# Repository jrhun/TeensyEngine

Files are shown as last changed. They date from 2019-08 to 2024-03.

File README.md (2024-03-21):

# TeensyEngine

TeensyEngine is primarily the software I use for my Totem Pole - named *The Orb*. 

gif

Included in this repository is a description of both the hardware and software features, including the MCAD/ECAD designs for everything.
It includes an emulator that's using OpenFrameworks for display and UI control, allowing easy testing and development.

<details>
<summary>  The Orb in the wild 
</summary>

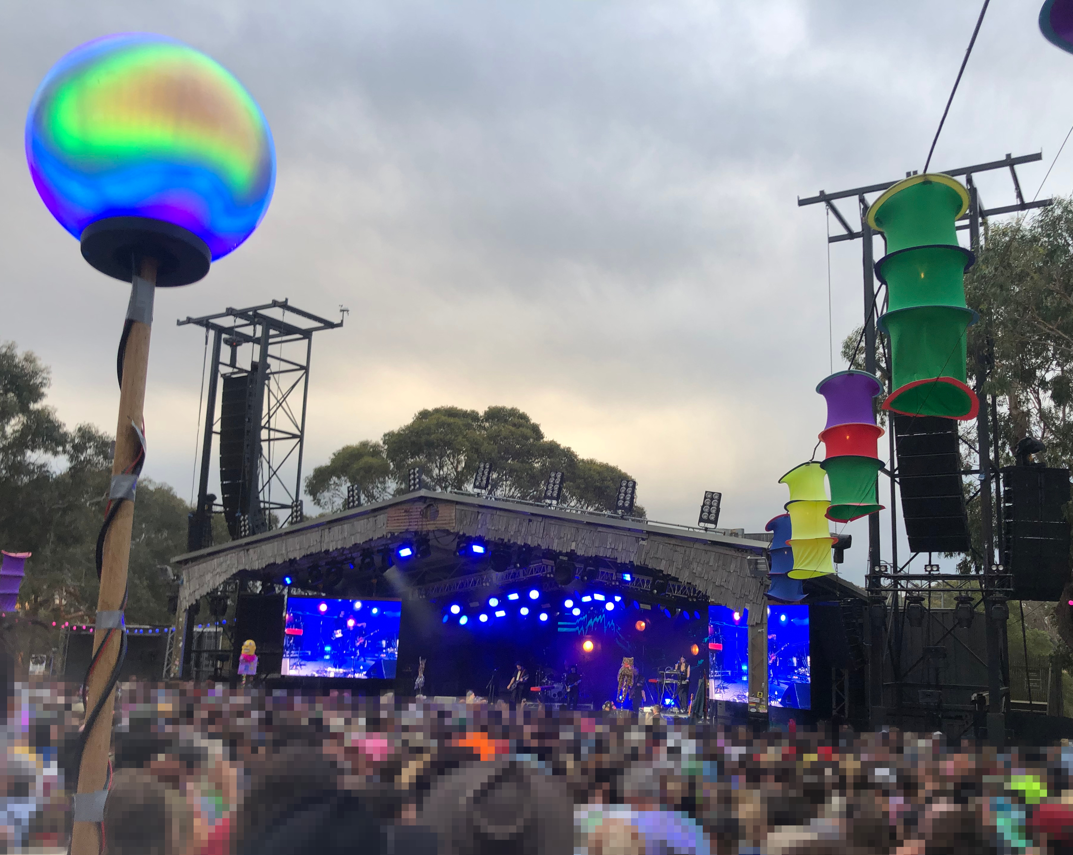
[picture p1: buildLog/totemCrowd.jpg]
totem crowd


</details>

## Contents 
- [About](#about)
- [Features](#features)
- [Hardware](#hardware)
- [Software](#software)
- [Credit](#credit)

## About
I took ~2000 LED lights and carefully shoved them inside a polycarbonate ball that was then placed on top of a stick and hooked up to a microprocessor and battery pack. Shockingly, it worked quite well! I use it as a Totem Pole for music festivals, come say hi if you see it!

This has been a multiyear endeavor  that I've slowly added more and more features to. It's the 4th iteration of the hardware including LEDs and controller/battery box. The first version was a couple of LEDs taped down inside two salad bowls - [how far this project has come since then!](buildLog/README.md#previous-versions)

Just a heads up - I'm an almost completely self taught programmer/3d modeler/electronics designer, there is a level of *jank* at times that should be expected to come of that, but overall I've been very pleased with the outcome! 
I will gladly take any suggestions or tips to improve my work, please comment any suggestions!

## Features

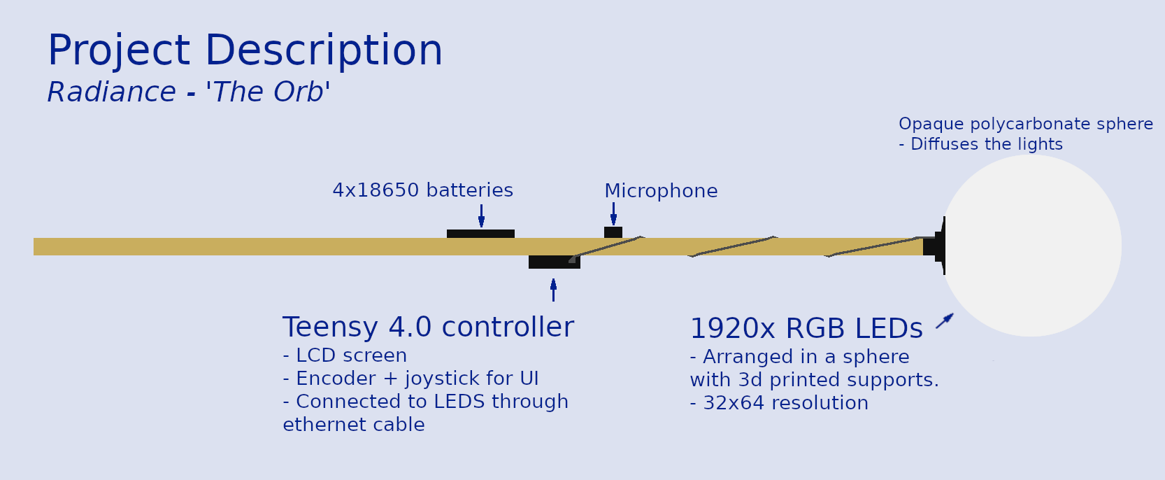
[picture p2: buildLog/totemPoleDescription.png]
description

- 25+ different patterns with the ability to change the colour palette being used for most patterns!
- Custom global blur/fade/glitter effects that can run on top of any pattern
- Text overlay onto patterns with the ability to enter custom text using the controller
- LCD Screen for changing settings/patterns + showing battery voltage and power usage
- Current sensor for monitoring power usage
- Encoder + buttons for navigating the UI
- An accelerometer (because why not)
- Microphone input 
- Wireless compatibility with NRF24L01 or ESP-01

<details open>
<summary> Videos of patterns on the hardware </summary>

https://user-images.githubusercontent.com/25134458/209674595-40512c94-f8f8-4173-94cc-6f29fc267113.mp4

https://user-images.githubusercontent.com/25134458/209741537-4713a7b6-7f0b-4868-8ff8-e278ab186450.mp4

https://user-images.githubusercontent.com/25134458/209743201-d97811d2-97b1-4fea-91a2-2c5a3d3df347.mp4

</details>

## Hardware
Some photos of the completed project can be found [here](buildLog/README.md).
I made a custom circuit board for connecting everything up along with a daughter board for [powering](#Power) the LEDs and providing the data through a CAT5 cable. 

#### Processor
A teensy 4.0 is the heart of the project, providing plenty of raw power to overcome my inefficient coding and push out LEDs while controlling  a UI.

#### Accessories
- Microphone - I can't remember what I'm using, one of the Sparkfun electret autogain boards. 
- NRF24l01 - used to connect wirelessly to LED headbands - allows you to change the patterns/brightness/colour of the headbands!
- ESP-01 - pins to connect to an ESP are broken out but not yet implemented
- ACS712 current sensor in series with the LEDs to measure power usage
- MSGEQ7 - the pinout is there but I haven't ended up using it yet
- ILI9341 colour TFT display 240x320 
- MPU9250 accelerometer

If trying to make this project, please confirm the pinout matches for the display and accelerometer! I got caught out and assumed they were the same for the two almost identical accelerometers I had, then needed to edit the circuit board. Also the linear regulator for the processor 5V line got way too hot so I changed it for a small buck convertor that (roughly) matched it's footprint. To be honest the circuit board could be redone with a teensy 4.1, as soldering the pogo pins to connect to the back of the teensy 4.0 was very tedious. 

#### Lights
Custom 3d printed scaffolding for strips of SK6805-2427 RGB LEDs, to hold them in a spherical shape inside a polycarbonate ball 25cm in diameter. They're held slightly back from the inside of the sphere to help diffuse the lights nicely. The scaffolding press fits together and tolerances were set for my 3d printer - YUMV. They're also held in place under slight compression from the globe. The LED strips are arranged as 30 to a strip with an offset pattern to reduce crowding at the poles, allowing for an effective resolution of 32H x 64W. See the [build details](buildLog/README.md#leds) for photos. 

The lights are from [Aliexpress](https://www.aliexpress.com/item/32818340106.html?spm=a2g0o.order_list.order_list_main.358.679f1802EQyb32), and were chosen for their high density (120/M, 8.33mm pitch) and thin strips (6mm width). 
Lights with a smaller pitch and thinner strip were outrageously expensive at the time I was purchasing LEDs, but have since come down in price somewhat... Version 5 [TBC](https://www.aliexpress.com/item/1005003798198621.html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)?

#### Power
The whole thing is powered by 4x 18650 batteries, I usually carry a spare set of 4x batteries for each night that it's used which usually lasts the night through.
There's a step-down converter in the controller providing 5V for the teensy and accessories. The full battery voltage is sent up to the LEDs where there is a separate step-down convertor. The benefit of the two power supplies is efficiency and stability, having a separate power source for the controller means its voltage doesn't dip when the LEDs draw a bunch of power. It also means I can provide much more power than *most* USB powerbanks, although I do want to try sending 20v from a 100w USB-C powerbank to the LEDs. Further details in the [build section.](buildLog/README.md#power)

## Software
The software include a basic emulator that runs the same UI and pattern software using OpenFrameworks to display the LEDs. 

<details open>
  <summary>Videos of the controller</summary>
 
  https://user-images.githubusercontent.com/25134458/209736586-94fa050d-8a2f-43fb-920e-38acb0f2c6ba.mp4
  
  https://user-images.githubusercontent.com/25134458/209676572-e61da54b-b9a8-4b95-bfd1-fcbd3a2c399e.mp4
  
</details>

### UI Pages
I've tried to organise the UI controls into roughly similar pages. The current battery voltage and current draw is shown in to top right corner, and the current FastLED FPS reading in the bottom right corner. The name of the totem is on the top of the screen, then the current page and a depiction of what page you're on. Joystick left/right changes the page, and up and down to select a setting. Hovering over a setting allows you to change a value with the encoder, or for some settings such as picking a pattern or palette you can press the joystick to enter a menu for that listing options. 

- **Pattern controls**
  - Select desired patterns from the list of patterns
  - Change overall brightness
  - Select a tempo + tap tempo
  - Change the tempo oscillator between square/ramp/sine etc...
  - Trigger ability to change a patterns settings (e.g. trigger different settings for a pattern without making a complete new one, see )
- **Colour controls**
  - Change current palette with a palette preview option
  - Blend amount when changing palette  over - quick or slow blend
  - Change how fast colours from a palette are cycled through
- **Text/FX controls**
  - Add transparent or opaque text over any pattern, or just blink text 
  - Text scroll speed
  - Select the text from a list or enter custom text (12 char max only!)
  - Global blur/fade/glitter effects
- **Wireless controls**
  - Control the wireless headbands I made using NRF24L01 communication
  - Change the pattern/colour/brightness of headbands in range
- **General settings**
  - LCD Backlight/Dither/Colour temp/Accelerometer/Save/load settings

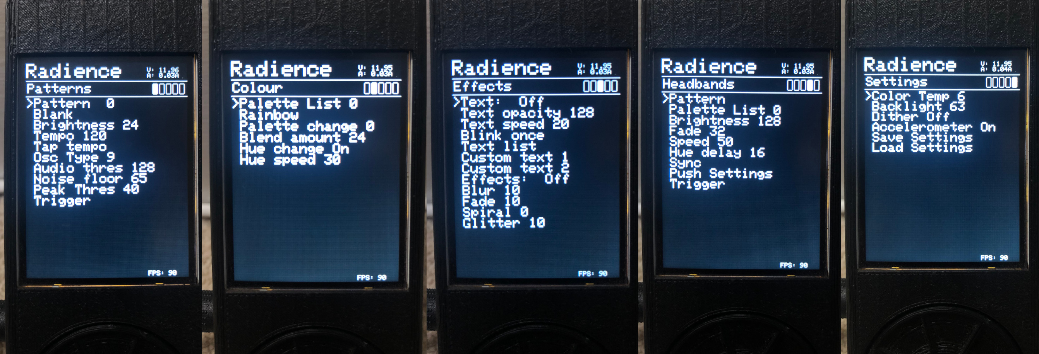
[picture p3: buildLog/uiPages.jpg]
UI example


### Adding a new pattern
The basic format for a pattern is a class inheriting from the `_Pattern` class, and should have the name for the pattern passed to it.

A `drawFrame()` function should be provided that is called to run the pattern. You can set the delay in msec for when to draw the next frame by the value you return. It also provides functions that are automatically called when starting or stopping a pattern, and a trigger option. Helper functions for drawing to the LED matrix are in the `gfx` class from `Graphics.h`. Try using `gfx.getColour(uint8_t offset)` for colours because this links in to the palette system. 

Include the code for a new pattern in `src/patterns/PatternController.h`, then add it as a member to the `PatternController` class and include it in the `patternList`
<details>
<summary>Example pattern</summary>
  
#### Blink all LEDs on/off
  ```
  class PatternBlink : public _Pattern {
  public:
    PatternBlink() : _Pattern("Blink") {}
    uint8_t drawFrame() {
      if (++count > 100) {
        count = 0;
        flip != flip;
      }
      if (flip) gfx.fill(gfx.getColour());
      else      gfx.fill(CRGB::Black);
      return returnVal; //default 10, 1000/10 = 100fps
    }
    uint8_t count = 0;
    bool flip = false;
  };
  ```
</details>

## Arduino code
The Teensyduino core was used for compiling and uploading.
`Graphics.h` does all the heavy lifting for helper functions. 

Arduino libraries used:
- [ILI9341_t3n](https://github.com/KurtE/ILI9341_t3n)
- [Encoder](https://github.com/PaulStoffregen/Encoder/blob/master/Encoder.h) from Paul Stroffregen
- [MPU9250](https://github.com/kriswiner/MPU9250) from kriswiner
- [FastLED](https://github.com/FastLED/FastLED)
- [Teensy ADC](https://github.com/pedvide/ADC)
- [RF24](https://github.com/nRF24/RF24)

## PC Emulator 

https://user-images.githubusercontent.com/25134458/209675905-0a1664af-fdfa-492f-b072-93c58537c89a.mp4

#### Requirements 
OpenFrameworks 0.10.1 was used for the graphics, with the ofxGui addon.

Visual Studio 2019 was used for compiling.
At one point I had it compiling on Mac XCode, but I haven't checked if that still works in a while.

<details open>
  <summary>The emulator has keyboard controls for the UI:</summary>
  
  - WASD: joystick up/left/down/right
  - Q/E: encoder rotate clockwise/counter clockwise
  - F: joystick press 
  - space: separate trigger, triggers effect on certain patterns (calls Pattern::Trigger())
  - Home/End/Del/PgDown: change pitch/roll level to emulate accelerometer changes
  - I: add random impulse to accelerometer data
  - 1 through 7: change beat type (RAMP, INVERSE_RAMP, TRIANGLE, SQUARE, SIN, TRIGGER, GATE, AUDIO, AUDIO_AVG, OFF)
</details>

## To-do list
- [ ] Add more photos of the completed totem to the build log
- [ ] More patterns
- [ ] Accelerometer fluid simulation - I've had multiple attempts but it just doesn't look right, a little beyond my abilities currently!
- [ ] More audio responsive patterns/improving audio code
- [ ] More patterns to respond to accelerometer 
- [ ] Make better use of global effects - the LEDs are double buffered but this is only really used for text currently
- [ ] Rotatable 3d view of the totem in the emulator rather than displaying as a flat 2d matrix

## Credit 
This project has taken inspiration from countless different sources. Please see [CONTRIBUTIONS.md](CONTRIBUTIONS.md) for full details.

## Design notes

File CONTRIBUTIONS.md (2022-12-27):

# Contributions

This project has been ongoing for years, I've taken bits and pieces of code that I've found useful or interesting and either used them as is, changed parts to fit, or re-written it completely. 
Unfortunately, much time has passed and I'm now I'm not entirely sure what parts are a complete rip off and what's original. 
If you see any of your code that I've used and not given credit for, please contact me so I can provide proper credit!

### 3d Engine Inspiration
[The Chili Framework 2016/3d Fundamentals]([https://github.com/planetchili/chili_framework](https://github.com/planetchili/3D_Fundamentals/tree/master/Engine)) was used as a basis for the 3d rendering code and helped me learn a lot about how a renderer works! The Chili Framework is under the same GNU General Public License v3.0 as the project.

### FastLED
FastLED is under the [MIT License](
MIT-License.md) (Copyright (c) 2013 FastLED). Various aspects of FastLEDs source code were copied for use with the emulator (essentially just any arduino references were removed). 

### Teensy core
Teensyduino is under the  GNU GENERAL PUBLIC LICENSE Version 2

### MPU9250 code
Example code taken from MPU9250_LPS25H_t3 by Kris Winer (license: Beerware)

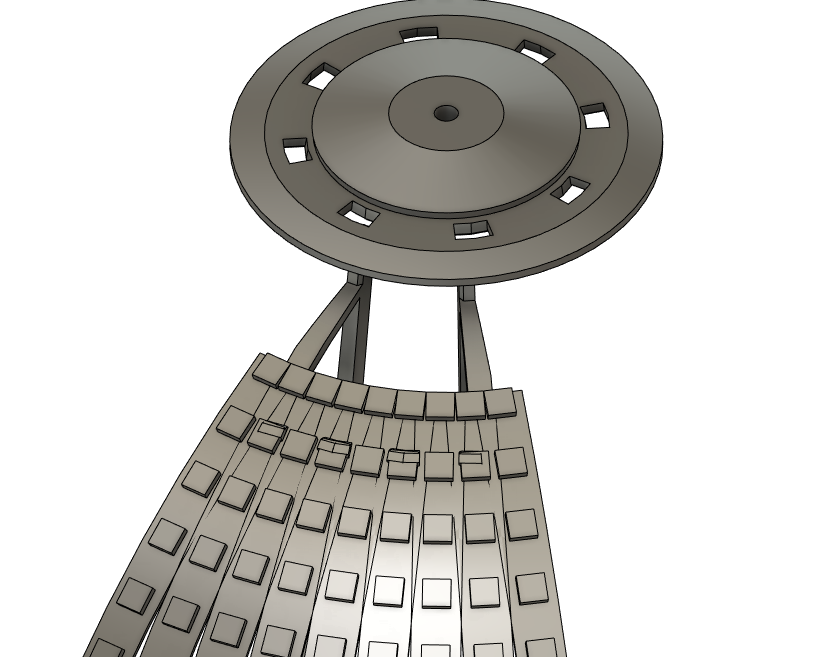
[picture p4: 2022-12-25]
buildLog/design-topLeds.PNG

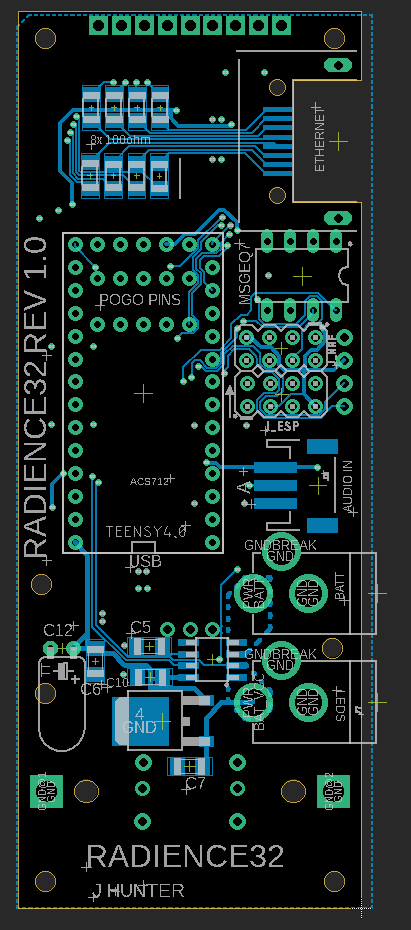
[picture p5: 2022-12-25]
buildLog/PCB_design-back.PNG

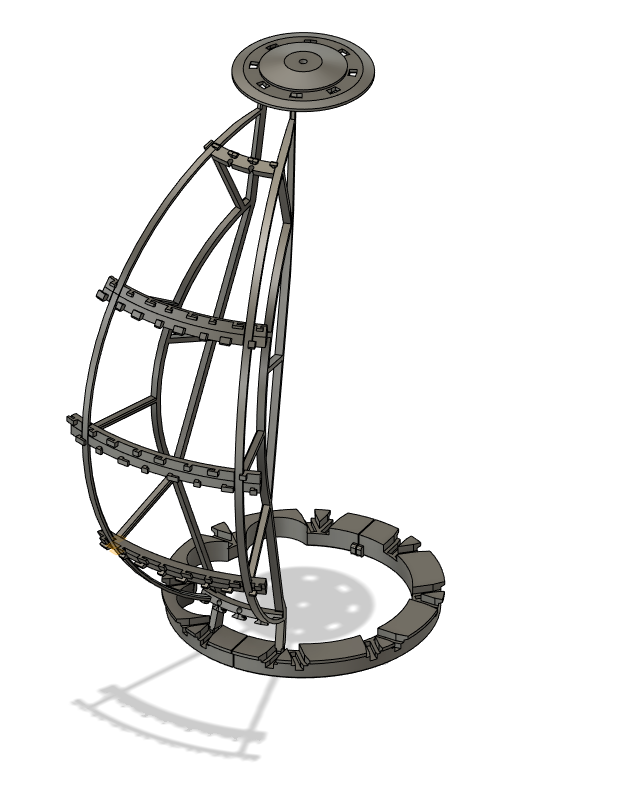
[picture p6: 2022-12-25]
buildLog/designSection.PNG

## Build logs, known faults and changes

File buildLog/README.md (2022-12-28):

# Build Log

## Contents
- [LEDS](#leds)
- [Power](#power)
- [Controller](#controller)
- [Previous Versions](#previous-versions)

## LEDS
I wanted as many LEDs as possible, and I wanted them held back enough from the polycarbonate shell to diffuse them nicely. 
I 3d modelled some scaffolding using ideas that had worked well from my previous attempts. The pieces press fit together, and once the LEDs are on, they're held in place quite firmly. It's built in 8 sections in order to fit inside the opening for the polycarbonate sphere (Only a ~10cm opening!), with a top and bottom piece to hold it in place. The top section can be tightened against the shell to help hold everything snug. 

### 3d Modelling the LEDs
This was one of the most complex models I'd made thus far, I needed to split the design up into sections that could break apart and be reconnected inside the globe, but I didn't want anything touching the sides as this would cast shadows and be visible (something V3 showed). This meant it needed a lot of rigidity to sandwich it inside the sphere from the top and bottom and not move around. I also found it difficult to model all the curves, there's not a lot of straight lines in this design and a lot of extruding along a path, meaning many extra steps for a simple feature.

I tried to design the profile to give as much space in the centre for my hand for getting inside, but still maintaining rigidity.
You can see how the LEDs interfere which each other at the top - it's wasted resolution up the top/bottom anyway and it gets crowded up there which is why the LEDs are offset from each other. 

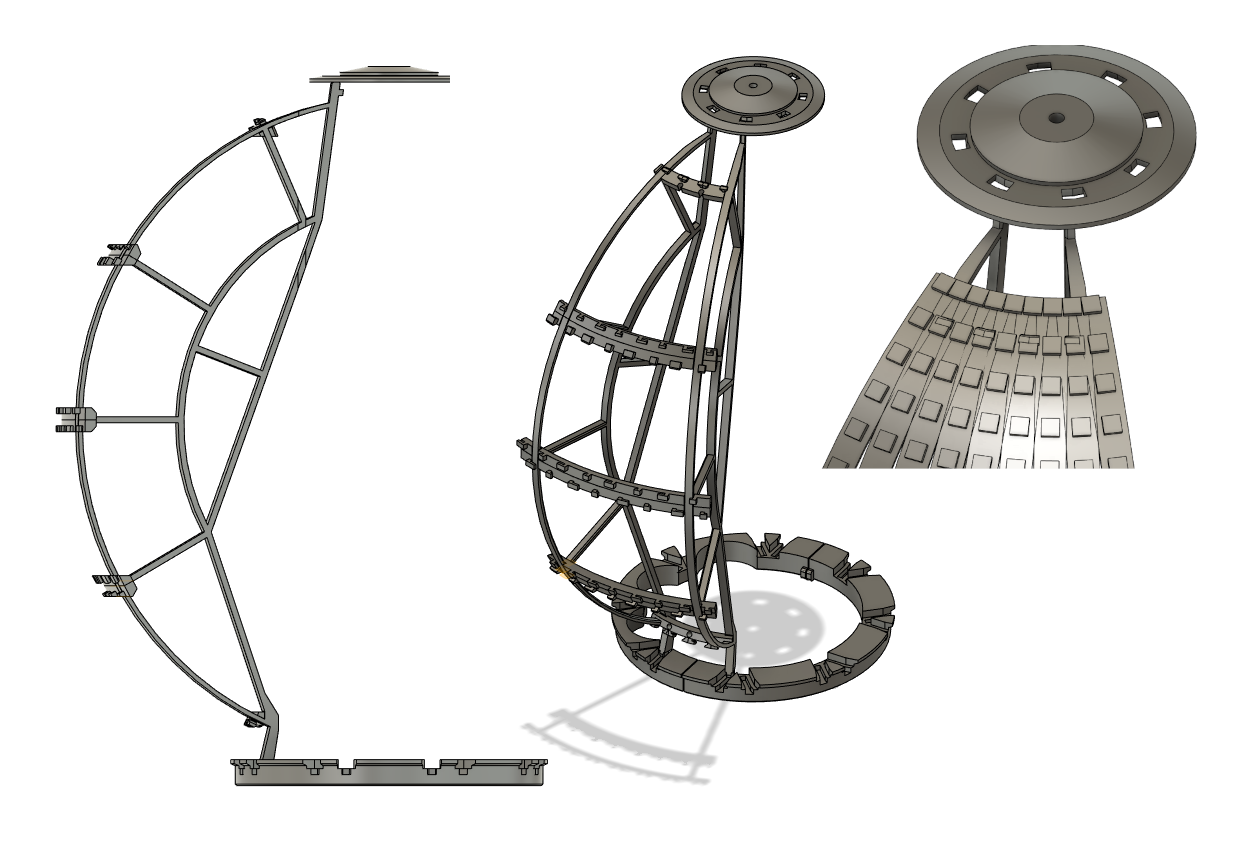
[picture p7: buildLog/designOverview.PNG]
Overview


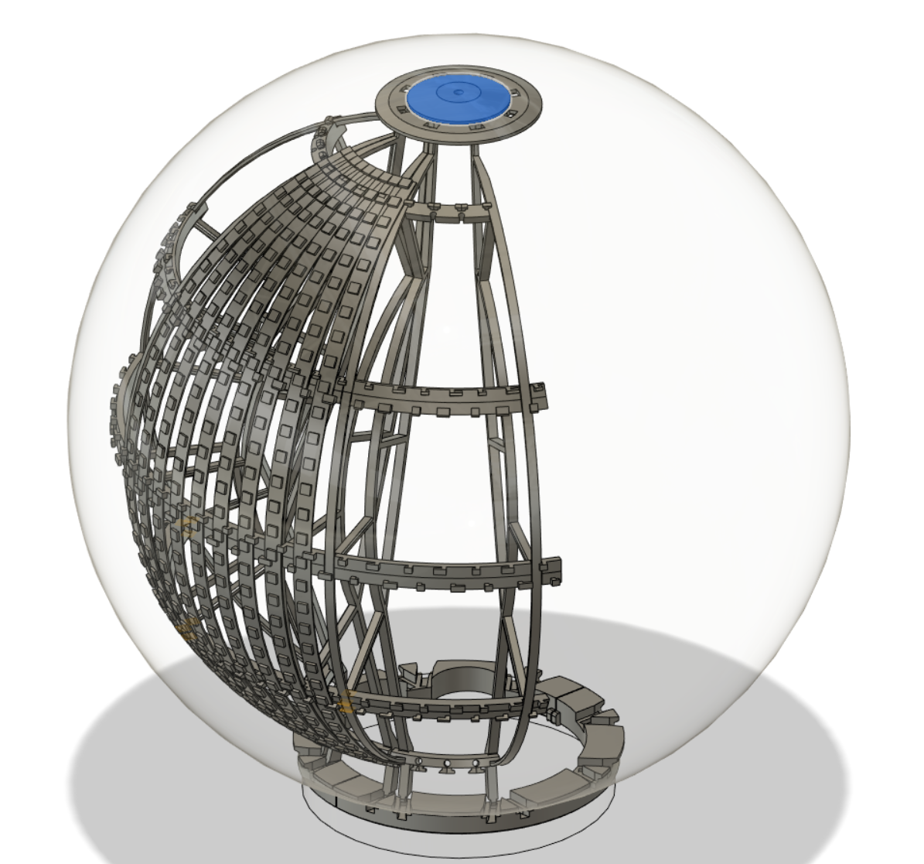
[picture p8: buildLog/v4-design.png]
Design


### Building the LED holders. 
One of the 8 sections printed. 

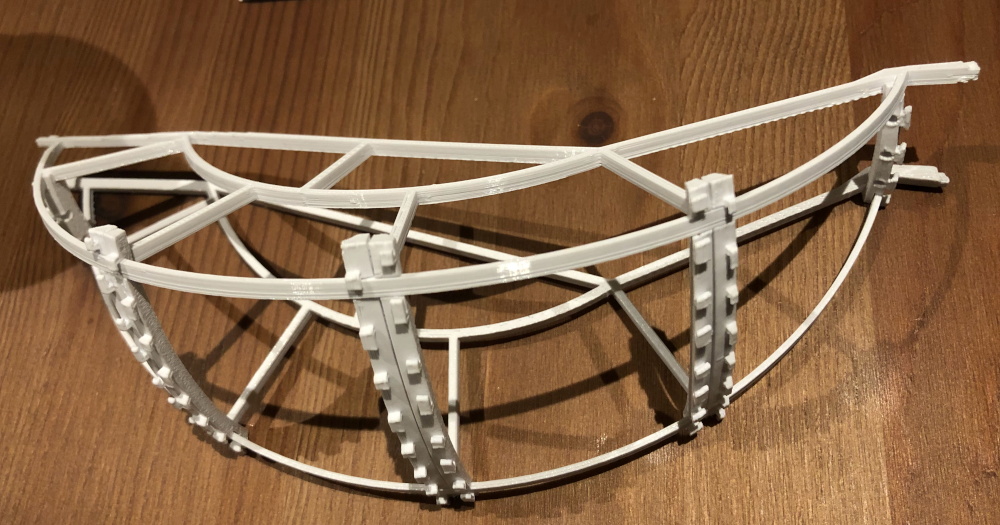
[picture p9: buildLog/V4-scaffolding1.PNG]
Scaffolding


These are SK6805-2427 RGB LEDs from [Aliexpress](https://www.aliexpress.com/item/32818340106.html?spm=a2g0o.order_list.order_list_main.358.679f1802EQyb32), the strips have a pitch of 8.33mm (120 LEDs per metre), and are only 6mm wide! In total I used 64x strips of 30, with separate power and data lines to each section of 8x strips. I won't lie, it took a long time to cut/strip the wires and solder everything all together, I probably didn't need to but I also added extra connections throughout the strips for distributing power/ground around and added stability in holding everything in place. 

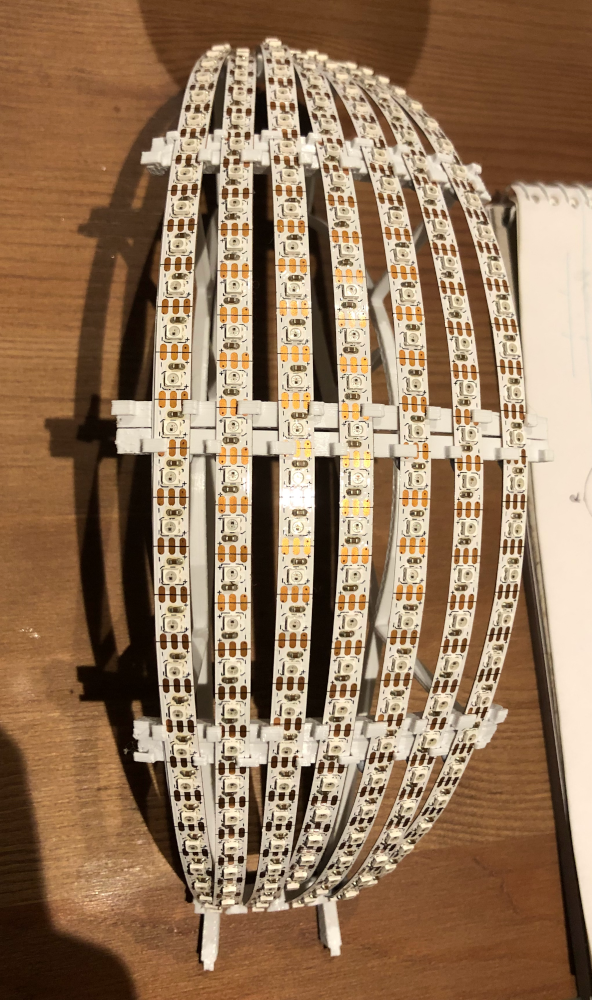
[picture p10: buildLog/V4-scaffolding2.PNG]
Scaffolding


Test fit of everything together. You can see how the LEDs are offset from each other to make space at the top/bottom. 

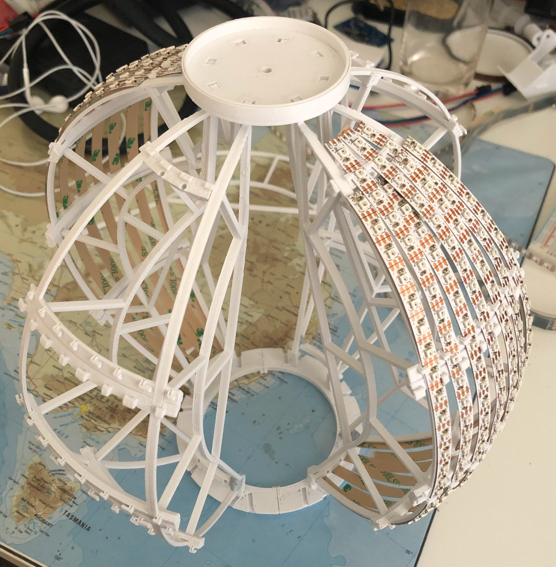
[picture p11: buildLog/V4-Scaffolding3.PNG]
Scaffolding


Checking if the LEDs all light up and my matrix XY() code works.
  
https://user-images.githubusercontent.com/25134458/209637888-4b88d217-abbb-4099-afa3-3a01516f0b0f.mp4

https://user-images.githubusercontent.com/25134458/209641775-9f14f9cc-60d3-4ed1-b838-ff2e159a5c03.mp4

Once I had each section built and connected, they needed to somehow be placed inside the shell and properly lined up. It was like building a ship in a bottle, but with lots of careful squeezing and manoeuvring all 8 sections were somehow in place and could be connected up to the bottom support to hold them in place. 

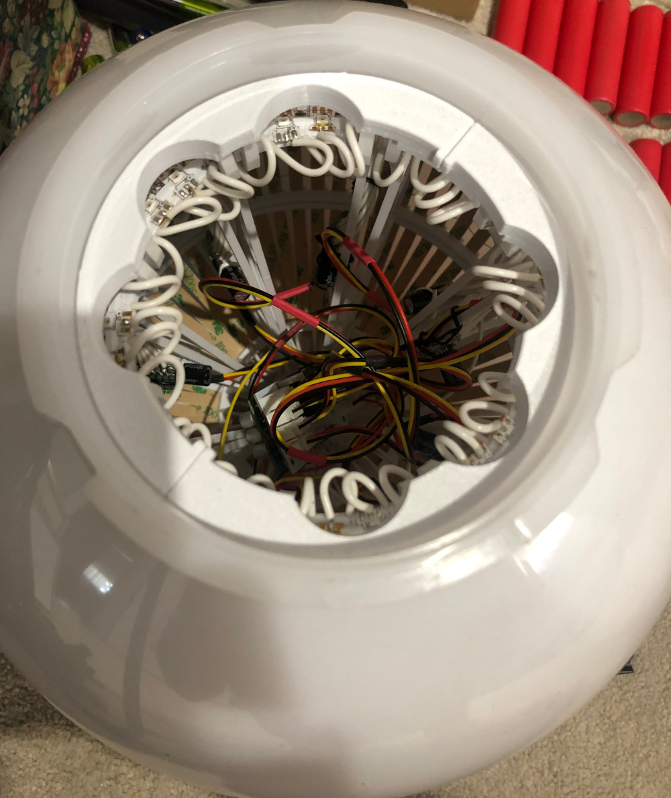
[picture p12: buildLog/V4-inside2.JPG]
Inside


I'm really happy with how the diffusion effect turned out, the lights are held back at almost the perfect distance. 

https://user-images.githubusercontent.com/25134458/209674595-40512c94-f8f8-4173-94cc-6f29fc267113.mp4

## Power
Previously I had powered V1 and V2 from initially 2xAA batteries. V3 kicked it up a notch going up to 288 LEDs so I went with 4xAAA batteries, but it still struggled if I turned up the brightness and would glitch out or freeze. It worked okay for V3 but moving up to ~2000 LEDs I needed something stronger. 

I used 4x 18650 batteries in a standard holder from amazon and changed it to a the barrel connector. The full battery voltage is sent up a wire to the LEDs at the top of the pole, and plugs into the daughter board up there. This allowed me to send the full battery voltage (~15V) up to the LEDs without needing a heavy gauge wire. There's a beefy [Pololu D24V150F5](https://www.pololu.com/product/2881) 5V 15A buck converter up there that does an amazing job for its size. This thing is expensive (and seems to have almost doubled in price since I bought one - ouch) but can handle up to 15A at 5V reliably and pretty efficiently, which is important since the LEDS draw ~0.5A (at 15V!) even when off with just their standby current! I guess 0.8ma per led adds up when there are 1920 of them... There's a separate step-down converter in the controller which avoids software freezes and glitches ~~if~~ when the LEDs draw too much current and dip the voltage. 

The connection for the LEDs is an ethernet cable, like with the [Teensy OctoWS2811](https://www.pjrc.com/store/octo28_adaptor.html). In theory, you should be able to connect an OctoWS2811 directly to the daughter board without any issues since I've used the same circuit as the OctoWS2811 to output data lines from the Teensy. Having 8 independent LED sections allowed 8 data wires for parallel output and a reasonable framerate, using a single data line for 1920 LEDs would have resulted in a framerate < 10fps.  

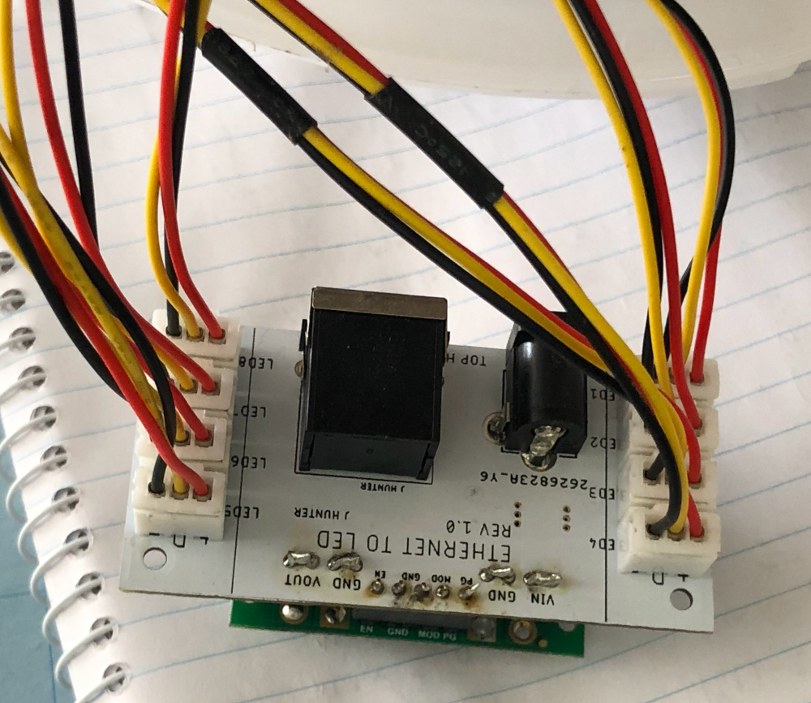
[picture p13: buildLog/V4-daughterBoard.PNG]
Daughter board


To avoid an absolute rats nest of wires at the top and bottom of the strips (128 wires for power/ground + data lines... no thanks!), I injected power into the middle of the strips. Each section of 8x strips (8 sections total) gets a data/power/ground connection from the daughter board, which goes to a small piece of protoboard with a capacitor and 8 ground/power wires for each strip. 

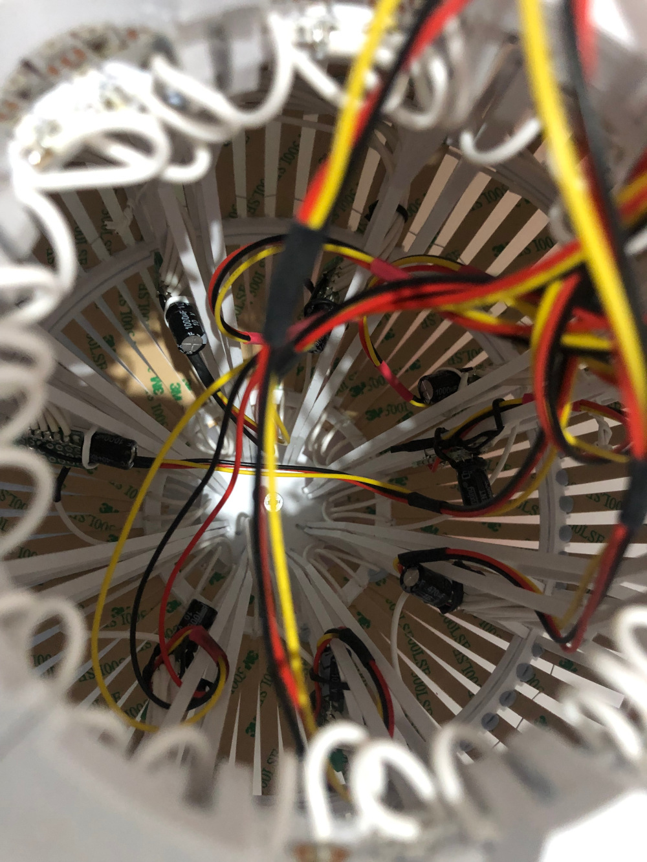
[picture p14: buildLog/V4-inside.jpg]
Inside


## Controller
I found a much larger 240x360 colour TFT that was the basis for the new controller, version 3 had a tiny 128x64 OLED screens that was monochrome and almost useless due to it's small size. It's much nicer actually being able to see the screen and having a colour screen allowed for a preview of the colour palettes. 

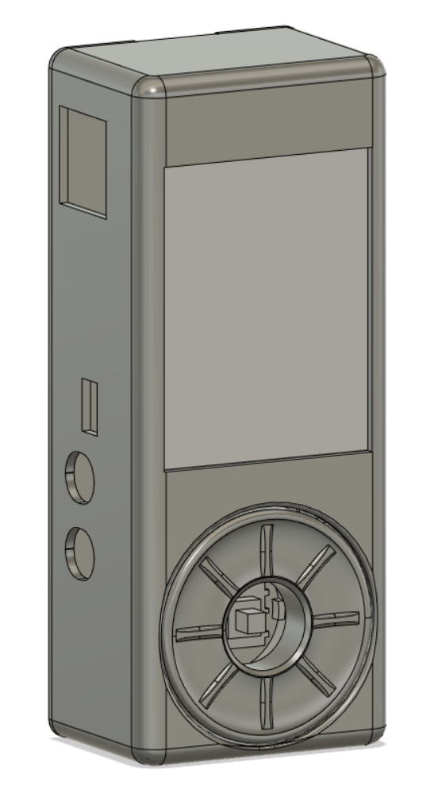
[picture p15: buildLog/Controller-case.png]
Case


I wanted input controls similar to an iPod classic, but designing a capacitive encoder seemed overkill and likely to become its own project, so I settled for a hollow encoder with a joystick in the centre. I was testing everything with an ESP32 initially, which worked okay but was missing some grunt. Around this time the Teensy 4.0 was released and it blew everything else out of the water performance wise, I pivoted over to use it instead and I'm so glad I did. 

The controller has pinouts for a NRF24L01, I've used this to connect to a set of headbands I made and can transmit colour/pattern change messages to them. 

<details open>
  <summary>Headbands details/photos</summary>
  
  The headbands have a mere 14 LEDs on them in a waterproof casing, connected to a small circuit board that holds an ATTINY and an NRF24L01, powered by 2xAA batteries in a 3d printed case. The case is a little bulky but has a nice curve that conforms to the back of your head. It's proven to be a pretty sturdy design, none of the 12 I made have broken yet... A couple patterns and the NRF code is at the limit of what the ATTINY can do, though it's impressive for a DIP8 chip! Technically powering the LEDs from 3V shouldn't work and I was prepared to squeeze a boost converter in there, but I got lucky and it worked fine for the LEDs I had on hand! 
  
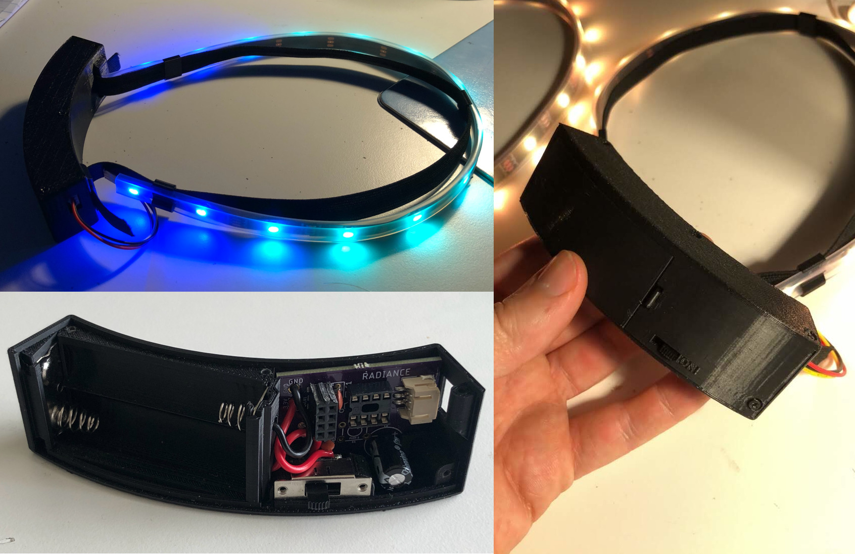
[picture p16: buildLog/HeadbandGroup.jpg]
  
  
  </details>

## Previous versions
### Version 1  
The initial design for a Totem poll called for lasers shining on a crystal in the centre, in an attempt to get a bunch of refraction and look interesting. This did not work at all. Luckily I had added a handful of WS2812 LEDs around, and at the last minute tapped them to the bottom so it at least lit up somewhat brightly. I  had spray painted the pole and bowls which was a poor choice as it would rub off onto your hands and made everything tacky - truly terrible!

### Version 2 
I scrapped the lasers, but went big on the LEDs which had worked the best. I found these excellent partially opaque polycarbonate shells 25cm in diameter, and tapped 9x strips of 8 WS2812 LEDs to the inside of it. It was much better than V1, but the tape came loose during the festival and some of the strips weren't always sitting up against the shell. This looked better than and ended up giving a nice diffuser effect to these lights to make them less of a pinpoint of light, giving me the inspiration for V3. 
  <details> 
    <summary>Photos</summary>
  
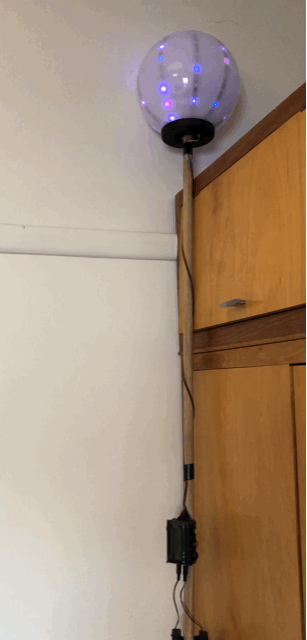
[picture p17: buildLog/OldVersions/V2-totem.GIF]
Version 2
  
  
  </details>
  
### Version 3 
This was where I started to get serious. If 72 LEDs looked so good, what if I had 4x as many?  I used 16x strips of 18 WS2812 leds, and 3D printed brackets to hold the LEDS in place and off the shell to get the diffuser effect. I designed my first circuit board for the control box to tidy things up and 3d printed a case for it as well. This version had enough resolution to even write basic words on it, but I knew I could squeeze in more LEDs if I tried...

  <details> 
    <summary>Photos</summary>
  
  Here you can see the layout of the LEDs, with the top piece holding them in place, and a spacer in the middle resting against the sphere shell. The 4 rods hold up the center piece, but it was too bulky and these rods too flimsy to keep reasonable tension. The middle spacers worked well but the part up against the shell cast a shadow from the LEDs to the side of them. This design had a lot of snap fits which worked surprisingly well overall. 
  
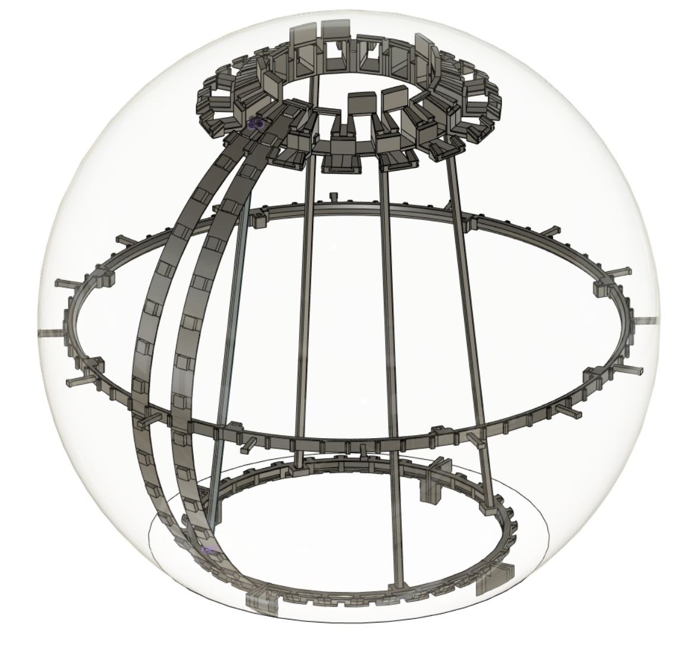
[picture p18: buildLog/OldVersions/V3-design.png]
Version 3
  
  
   You can see how the support rods are bending and the obligatory token capacitor for WS2812 leds. 
  
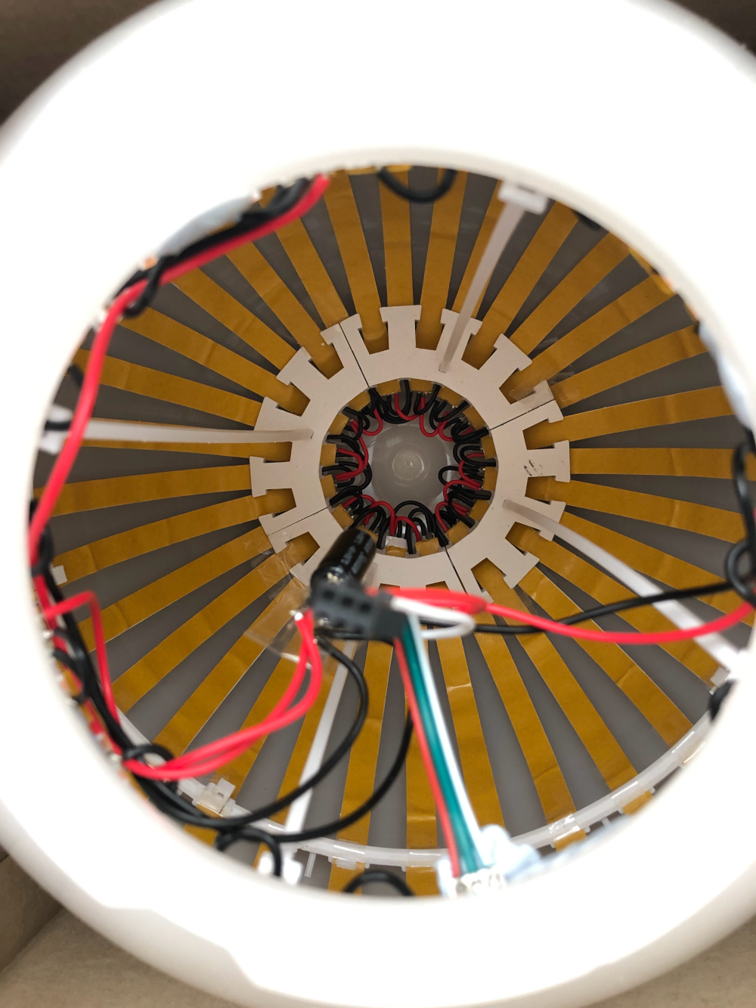
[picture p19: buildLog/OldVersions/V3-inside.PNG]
Version 3
  

https://user-images.githubusercontent.com/25134458/209637023-156c7152-dfb4-41f7-a652-bb55d0df1f59.mp4

  </details>

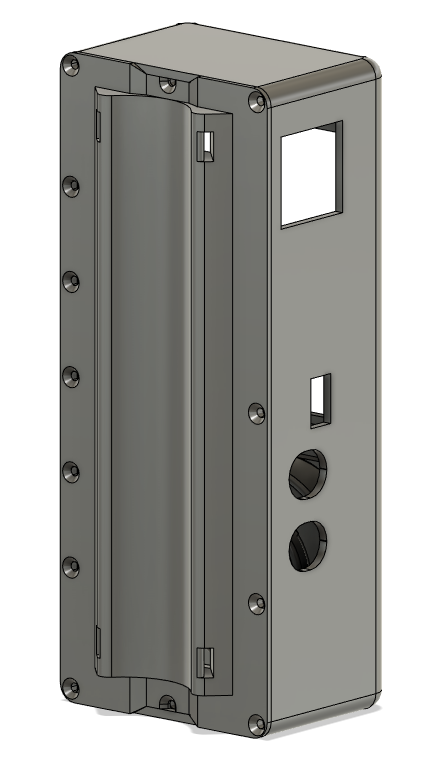
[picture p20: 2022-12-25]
buildLog/Controller-case-back.PNG

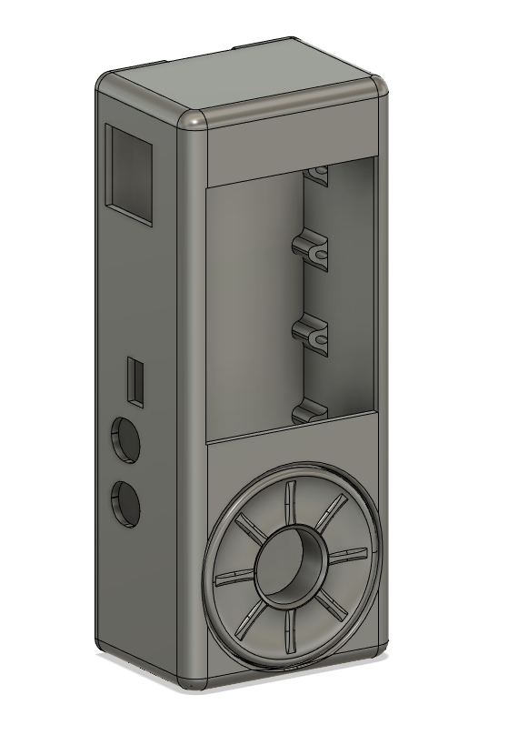
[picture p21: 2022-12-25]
buildLog/Controller-case-front.PNG

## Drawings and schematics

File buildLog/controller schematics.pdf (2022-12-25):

# 5 P$1 GND@¹*2

A

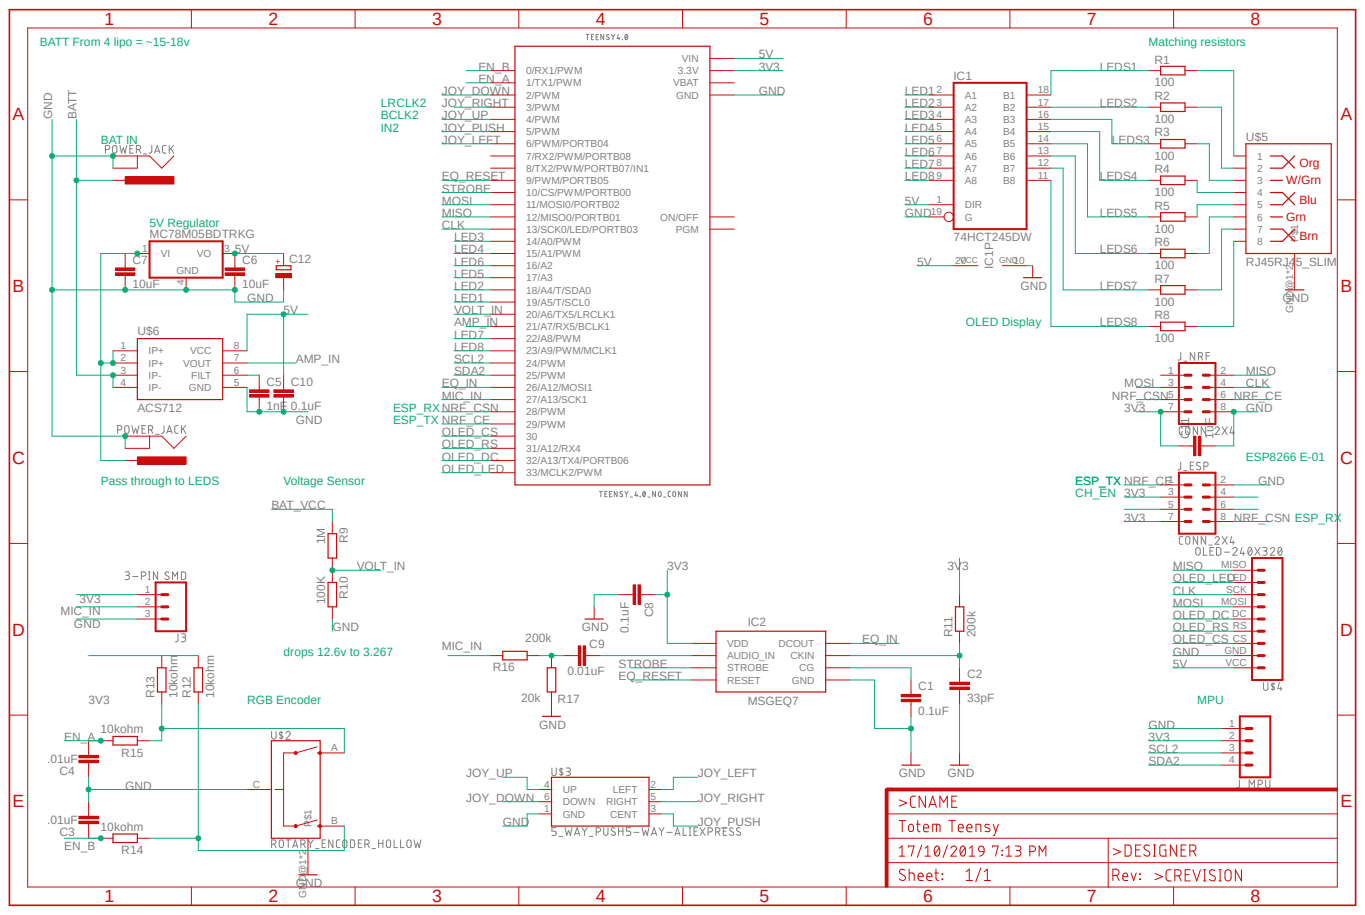
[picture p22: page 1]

BATT From 4 lipo = ~15-18v | | Matching resistors

Pass through to LEDS

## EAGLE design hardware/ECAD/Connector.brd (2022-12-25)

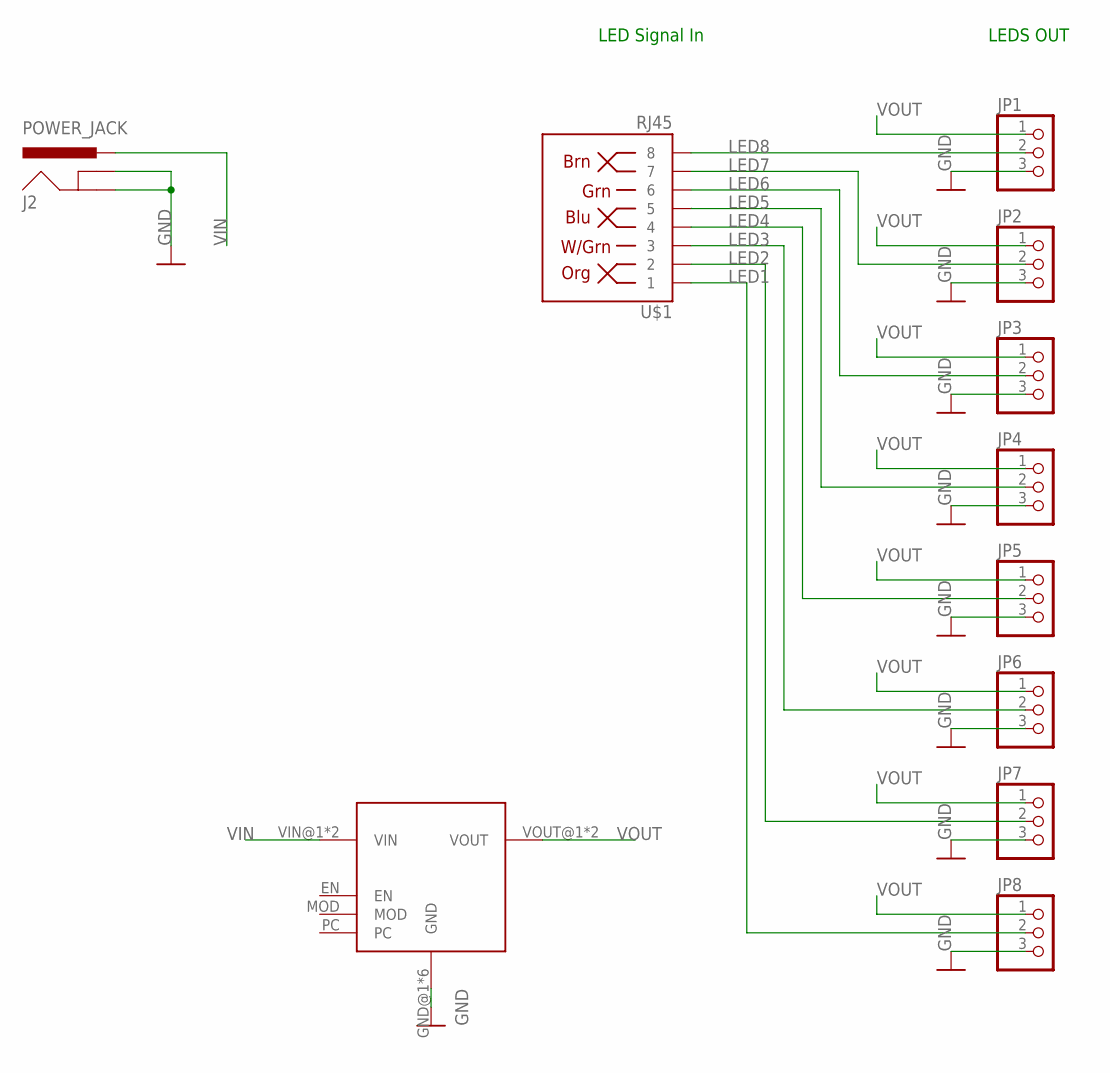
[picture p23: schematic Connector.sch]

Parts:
J2: POWER_JACK; POWER_JACK_PTH
JP1, JP2, JP3, JP4, JP5, JP6, JP7, JP8: PINHD-1X3; 1X03
U$1: RJ45; RJ45_WINGS
U$2: 5V-15A-VOLTAGE_CONVERTER; D24V150F

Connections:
GND: J2.GND, J2.GNDBREAK, JP1.3, JP2.3, JP3.3, JP4.3, JP5.3, JP6.3, JP7.3, JP8.3, U$2.GND@1 (GND), U$2.GND@2 (GND), U$2.GND@3 (GND), U$2.GND@4 (GND), U$2.GND@5 (GND), U$2.GND@6 (GND)
LED1: JP8.2, U$1.1
LED2: JP7.2, U$1.2
LED3: JP6.2, U$1.3
LED4: JP5.2, U$1.4
LED5: JP4.2, U$1.5
LED6: JP3.2, U$1.6
LED7: JP2.2, U$1.7
LED8: JP1.2, U$1.8
VIN: J2.PWR, U$2.VIN@1 (VIN), U$2.VIN@2 (VIN)
VOUT: JP1.1, JP2.1, JP3.1, JP4.1, JP5.1, JP6.1, JP7.1, JP8.1, U$2.VOUT@1 (VOUT), U$2.VOUT@2 (VOUT)

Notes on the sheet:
LED Signal In
LEDS OUT

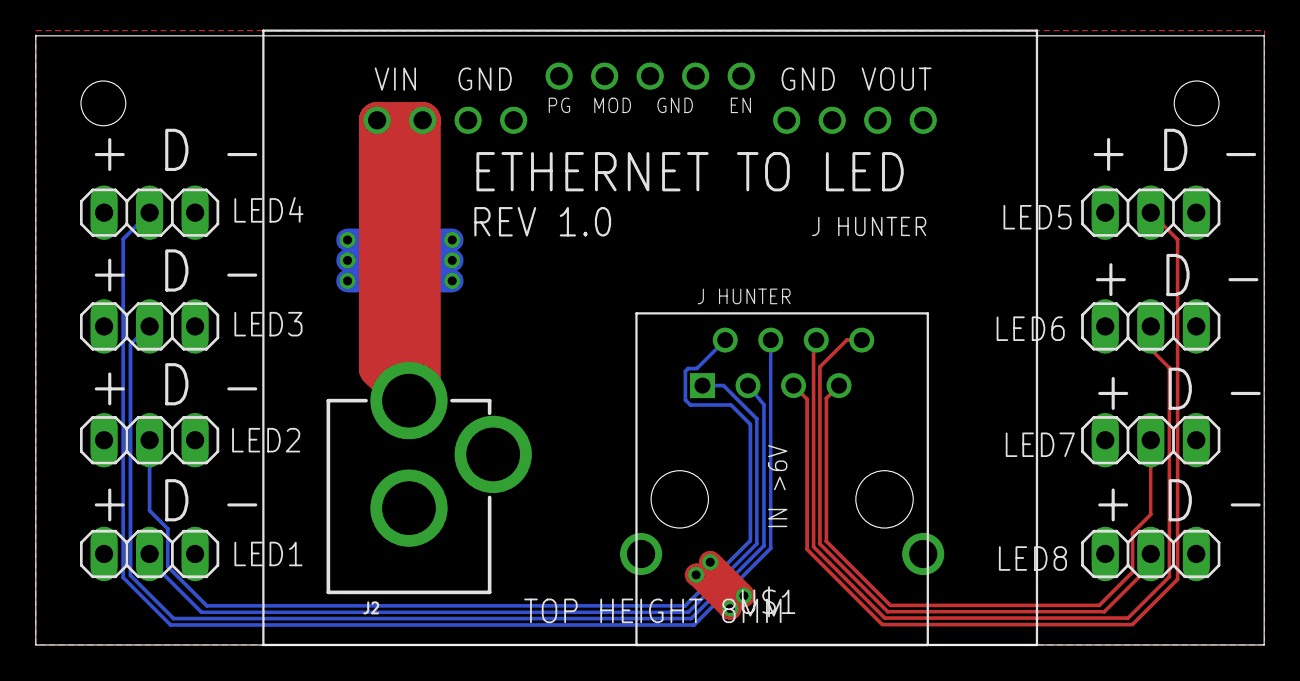
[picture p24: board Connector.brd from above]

Board: 2 copper layers, 68.6 x 34.0 mm, 11 parts (0 on the bottom side), 11 nets.

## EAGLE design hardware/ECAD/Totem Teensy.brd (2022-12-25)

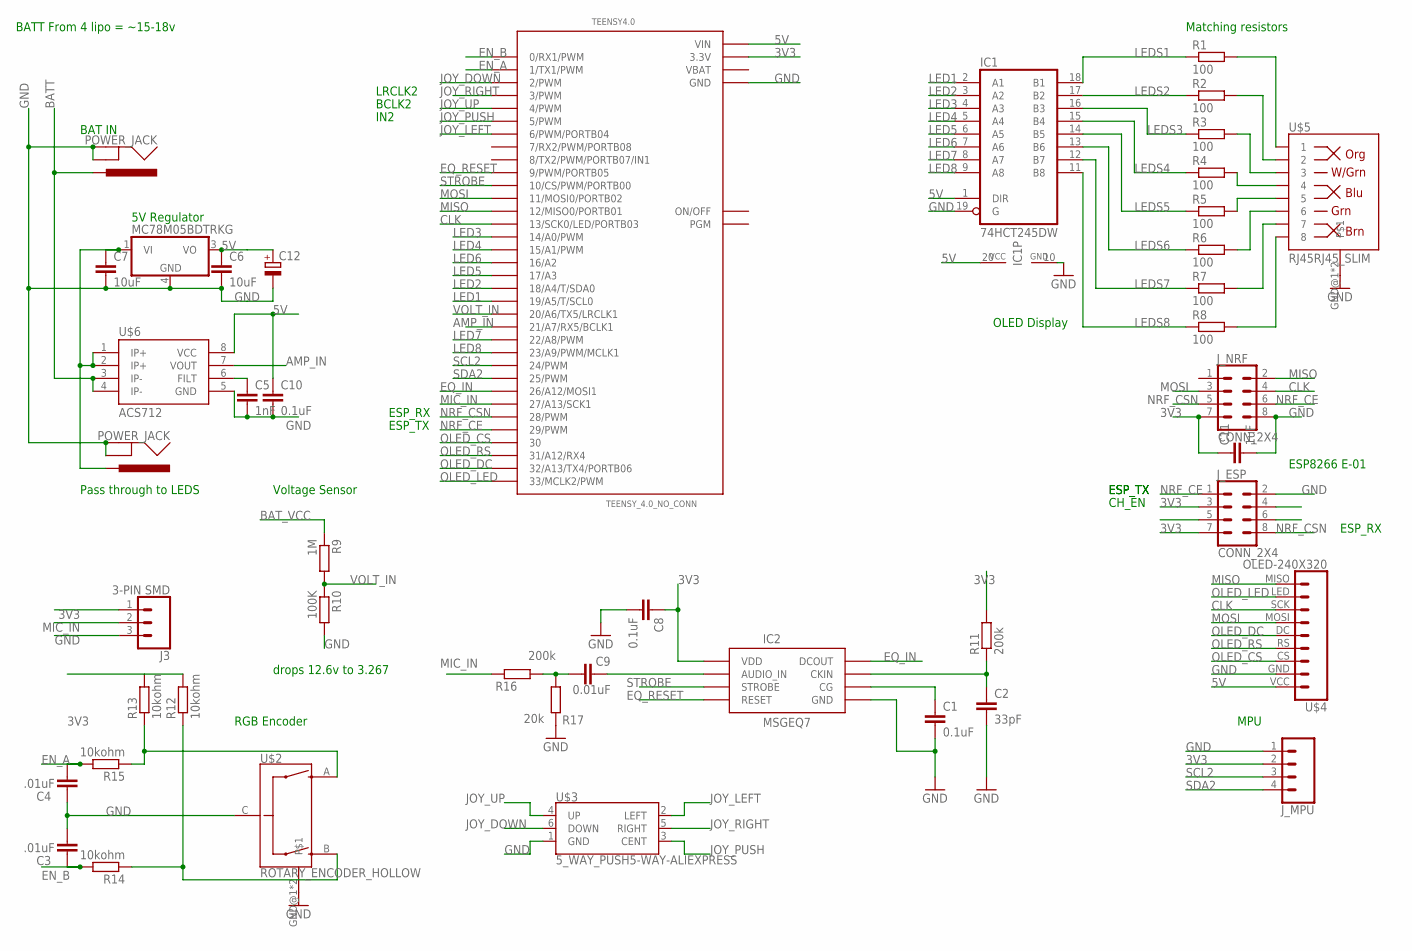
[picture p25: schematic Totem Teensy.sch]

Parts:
C1, C8, C10: 0.1uF; C1206
C2: 33pF; C1206
C3, C4: .01uF; C1206
C5: 1nF; C1206
C6, C7: 10uF; C1206
C9: 0.01uF; C1206
C11: 1uF; C1206
C12: CPOL-EUTT2D5L; TT2D5L
IC1: 74HCT245DW; SO20W
IC2: MSGEQ7DIP; DIL08
IC3: MC78M05BDTRKG; DPACK_3
J1, J7: POWER_JACK; POWER_JACK_PTH
J3: 3-PIN SMD; JST-3-SMD
J_ESP: CONN_2X4; 2X4
J_MPU: CONN_04; 1X04
J_NRF: CONN_2X4; 2X4
R1, R2, R3, R4, R5, R6, R7, R8: 100; R1206
R9: 1M; M1206
R10: 100K; M1206
R11, R16: 200k; R1206
R12, R13, R14, R15: 10kohm; R1206
R17: 20k; R1206
TEENSY4.0: TEENSY_4.0_NO_CONN; TEENSY_4.0
U$2: ROTARY_ENCODER_HOLLOW; HOLLOW_ENCODER30R
U$3: 5_WAY_PUSH5-WAY-ALIEXPRESS; 5-WAY_PTH2
U$4: OLED-240X320; OLED_240X320
U$5: RJ45RJ45_SLIM; RJ45_SLIM
U$6: ACS712; SO08

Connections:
3V3: C8.1, C11.1, IC2.1 (VDD), J3.1, J_ESP.3, J_ESP.7, J_MPU.2, J_NRF.7, R11.2, R12.2, R13.2, TEENSY4.0.3.3@0 (3.3V), TEENSY4.0.3.3@1 (3.3V)
5V: C6.1, C10.1, C12.+, IC1.1 (DIR), IC1.20 (VCC), IC3.3 (VO), TEENSY4.0.VIN, U$4.VCC, U$6.8 (VCC)
AMP_IN: TEENSY4.0.21/A7 (21/A7/RX5/BCLK1), U$6.7 (VOUT)
BATT: J1.PWR, U$6.3 (IP-), U$6.4 (IP-)
BAT_VCC: C7.1, IC3.1 (VI), J7.PWR, R9.1, U$6.1 (IP+), U$6.2 (IP+)
CLK: J_NRF.4, TEENSY4.0.13 (13/SCK0/LED/PORTB03), U$4.SCK (CLK)
EN_A: C4.1, R15.2, TEENSY4.0.1 (1/TX1/PWM)
EN_B: C3.2, R14.2, TEENSY4.0.0 (0/RX1/PWM)
EQ_IN: IC2.3 (DCOUT), TEENSY4.0.26 (26/A12/MOSI1)
EQ_RESET: IC2.7 (RESET), TEENSY4.0.9 (9/PWM/PORTB05)
GND: C1.2, C2.2, C3.1, C4.2, C5.2, C6.2, C7.2, C8.2, C10.2, C11.2, C12.-, IC1.10 (GND), IC1.19 (G), IC2.2 (GND), IC3.4 (GND), J1.GND, J1.GNDBREAK, J3.3, J7.GND, J7.GNDBREAK, J_ESP.2, J_MPU.1, J_NRF.8, R10.2, R17.2, TEENSY4.0.GND@0 (GND), TEENSY4.0.GND@1 (GND), TEENSY4.0.GND@2 (GND), U$2.C, U$2.GND@1, U$2.GND@2, U$3.1 (GND), U$4.GND, U$5.GND@1, U$5.GND@2, U$6.5 (GND)
JOY_DOWN: TEENSY4.0.2 (2/PWM), U$3.6 (DOWN)
JOY_LEFT: TEENSY4.0.6 (6/PWM/PORTB04), U$3.2 (LEFT)
JOY_PUSH: TEENSY4.0.5 (5/PWM), U$3.3 (CENT)
JOY_RIGHT: TEENSY4.0.3 (3/PWM), U$3.5 (RIGHT)
JOY_UP: TEENSY4.0.4 (4/PWM), U$3.4 (UP)
LED1: IC1.2 (A1), TEENSY4.0.19/A5 (19/A5/T/SCL0)
LED2: IC1.3 (A2), TEENSY4.0.18/A4 (18/A4/T/SDA0)
LED3: IC1.4 (A3), TEENSY4.0.14/A0 (14/A0/PWM)
LED4: IC1.5 (A4), TEENSY4.0.15/A1 (15/A1/PWM)
LED5: IC1.6 (A5), TEENSY4.0.17/A3
LED6: IC1.7 (A6), TEENSY4.0.16/A2
LED7: IC1.8 (A7), TEENSY4.0.22/A8 (22/A8/PWM)
LED8: IC1.9 (A8), TEENSY4.0.23/A9 (23/A9/PWM/MCLK1)
LEDS1: IC1.18 (B1), R1.1
LEDS2: IC1.17 (B2), R2.1
LEDS3: IC1.16 (B3), R3.1
LEDS4: IC1.15 (B4), R4.1
LEDS5: IC1.14 (B5), R5.1
LEDS6: IC1.13 (B6), R6.1
LEDS7: IC1.12 (B7), R7.1
LEDS8: IC1.11 (B8), R8.1
MIC_IN: J3.2, R16.2, TEENSY4.0.27 (27/A13/SCK1)
MISO: J_NRF.2, TEENSY4.0.12 (12/MISO0/PORTB01), U$4.MISO
MOSI: J_NRF.3, TEENSY4.0.11 (11/MOSI0/PORTB02), U$4.MOSI
unnamed: R1.2, U$5.8 (1)
unnamed: R2.2, U$5.7 (2)
unnamed: R4.2, U$5.5 (4)
unnamed: R3.2, U$5.6 (3)
unnamed: R5.2, U$5.4 (5)
unnamed: R6.2, U$5.3 (6)
unnamed: R7.2, U$5.2 (7)
unnamed: R8.2, U$5.1 (8)
unnamed: C9.2, R16.1, R17.1
unnamed: C9.1, IC2.5 (AUDIO_IN)
unnamed: C5.1, U$6.6 (FILT)
unnamed: R13.1, R15.1, U$2.A
unnamed: R12.1, R14.1, U$2.B
unnamed: C2.1, IC2.8 (CKIN), R11.1
unnamed: C1.1, IC2.6 (CG)
NRF_CE: J_ESP.1, J_NRF.6, TEENSY4.0.29 (29/PWM)
NRF_CSN: J_ESP.8, J_NRF.5, TEENSY4.0.28 (28/PWM)
OLED_CS: TEENSY4.0.30, U$4.CS
OLED_DC: TEENSY4.0.32 (32/A13/TX4/PORTB06), U$4.DC
OLED_LED: TEENSY4.0.33 (33/MCLK2/PWM), U$4.LED
OLED_RS: TEENSY4.0.31 (31/A12/RX4), U$4.RS
SCL2: J_MPU.3, TEENSY4.0.24 (24/PWM)
SDA2: J_MPU.4, TEENSY4.0.25 (25/PWM)
STROBE: IC2.4 (STROBE), TEENSY4.0.10 (10/CS/PWM/PORTB00)
VBAT: TEENSY4.0.VBAT
VOLT_IN: R9.2, R10.1, TEENSY4.0.20/A6 (20/A6/TX5/LRCLK1)

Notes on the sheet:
Matching resistors
RGB Encoder
OLED Display
BATT From 4 lipo = ~15-18v
5V Regulator
Pass through to LEDS
BAT IN
ESP8266 E-01
ESP_TX
ESP_RX
MPU
BCLK2
IN2
LRCLK2
Voltage Sensor
drops 12.6v to 3.267
CH_EN

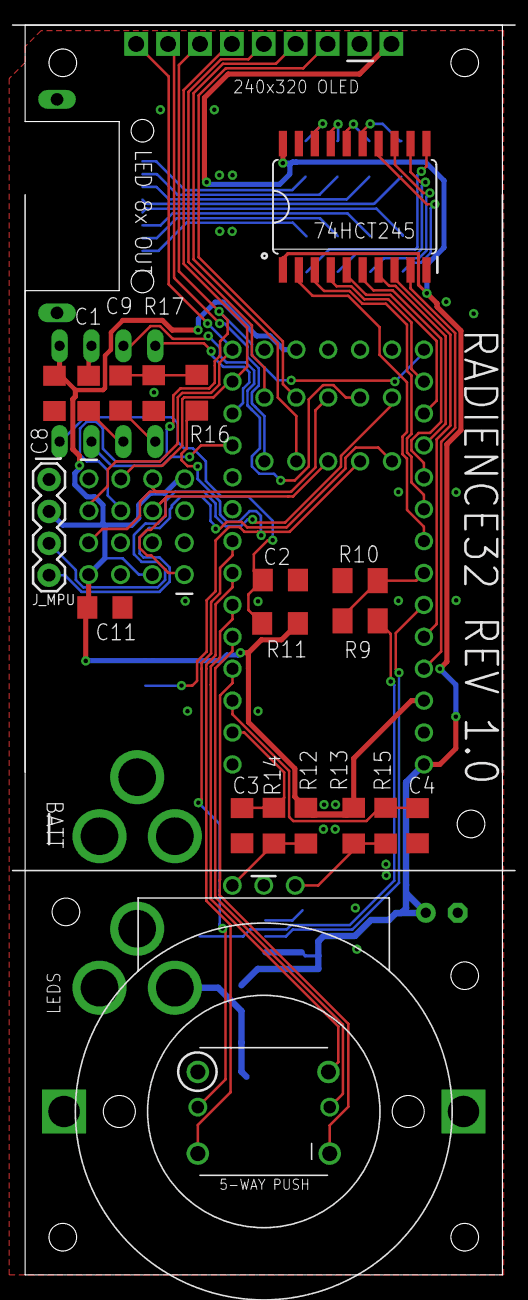
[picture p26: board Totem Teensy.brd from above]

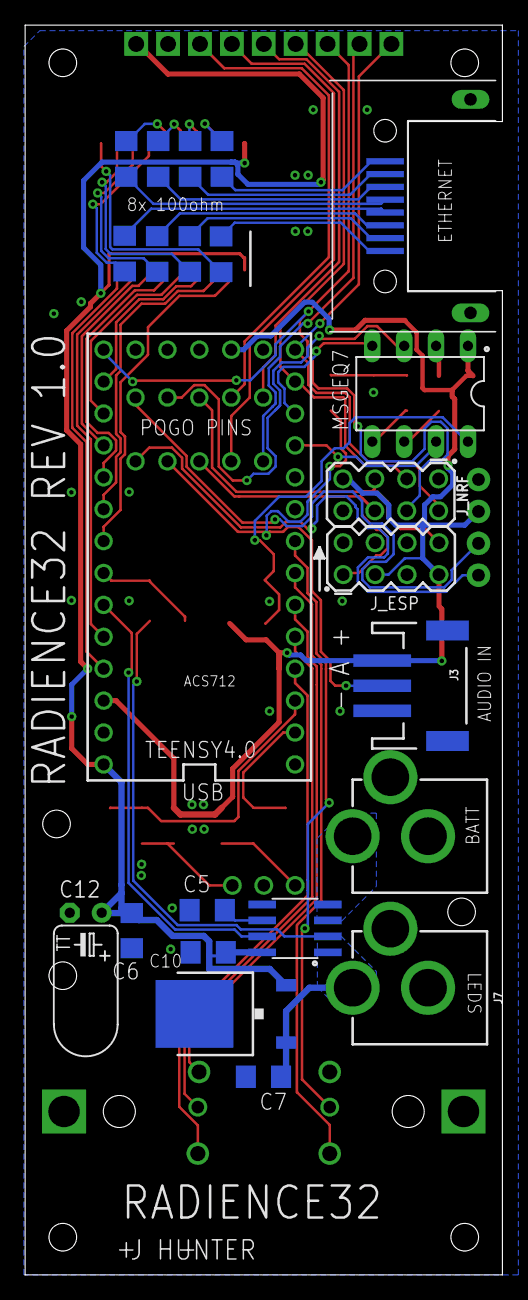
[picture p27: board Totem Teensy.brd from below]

Board: 2 copper layers, 38.0 x 99.5 mm, 44 parts (23 on the bottom side), 60 nets.

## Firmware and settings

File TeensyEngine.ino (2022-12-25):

#include "data.h"
//#include "ledControl.h"
#include "audio.h"
#include "motion.h"

#include "src\Patterns\PatternController.h"
#include "ui.h"

//#include "headbands.h"



void setup() {
  Serial.begin(115200);
  delay(200);
  Serial.println("Started");
  
  audioSetup();
  
//  pinMode(MIC_IN_PIN, INPUT);
//  pinMode(EQ_AUDIO_PIN, INPUT);

  gfx.init();
//  ledControl.init();
  uiSetup();

  initMPU();

  //ADC setup
  //A6 volt, A7 amp on ADC0, A13 audio on ADC1


  
}

void loop() {
  audioLoop();
  
  EVERY_N_MILLISECONDS(50) {
    if (Data::accelerometer)
      getPitchBasic();
    else {
      Data::pitch = beatsin8(30, 0, 60) - 30;
      Data::roll = beatsin8(32, 0, 60) - 30;
    }
  }

//  if (Data::audioOn) audioLoop();
//  if (Data::MPUOn) updateMPU();
  patterns.run();
  uiLoop();
  
//  EVERY_N_SECONDS(Data::changePaletteDelay ? Data::changePaletteDelay : 1) {
//  	thistimer.setPeriod
//  }

  

//  if (Data::sendUpdate) {
//    hbUpdate(Data::sendUpdate);
//    Data::sendUpdate = 0;
//  }
//  
//  EVERY_N_MILLISECONDS(1000) {
//    Serial.print("FPS: ");
//    Serial.println(FastLED.getFPS());
////    tftDisplayFPS();
//  }
}

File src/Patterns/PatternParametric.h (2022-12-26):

#pragma once

#include "Pattern.h"
#include "../../data.h"

extern float GuiVars1;
extern float GuiVars2;
extern float GuiVars3;
extern float GuiVars4;
extern float GuiVars5;
extern float GuiVars6;

class PatternParametric : public _Pattern {
public:
	PatternParametric() : _Pattern("Parametric Lines") {}
	//draws parametric lines in the xyz space and rotates them around the sphere

	uint8_t drawFrame() {
		if (!_Pattern::useCustomEffect) {
			gfx.fade(30);
			gfx.blur(90);
		}
		gfx.resetZ();
		const int maxI = 100; //draw 100 lines
		float step = (PI) / (maxI - 1);
		m = Mat3::RotationY(angle)  * Mat3::RotationX(angle);
		for (int i = 0; i < maxI; i++) {
			float t = offset + i * step;
			//CRGB c1 = gfx.getColour(i / 2);
			//CRGB c2 = gfx.getColour(i / 2 + 40);
			//c1.nscale8_video(min(i*4, 255));
			//c2.nscale8_video(min(i * 4, 255));
			drawLine(t, i / 1, i / 1 + 32, min(i * 12, 255));
		}
		offset += 0.1;

		float radius = myMap(Data::sampleAvg, 0, Data::audioThreshold * 2, 2.5, 1.8, true);

		centerA.x = radius * cos(angle + PI);
		centerA.z = radius * sin(angle + PI);

		centerB.x = radius * cos(angle + PI + PI);
		centerB.z = radius * sin(angle + PI + PI);

		angle += 0.005;
		if (angle >= TWO_PI)
			angle -= TWO_PI;
#if defined(ESP32) || defined(CORE_TEENSY)
		return (1000/60);
#else 
		return returnVal;
#endif
	}

	void drawLine(float t, uint8_t hue1, uint8_t hue2, uint8_t fade) {
		//Vec3 a(sin(t) * GuiVars1, cos(t / 2) * GuiVars2, cos(t) * GuiVars3); // 1.6/0.6/1.25
		//Vec3 b(sin(t) * GuiVars4, sin(t / 2) * GuiVars5, cos(t) * GuiVars6); // 0.87/1.25/1.15

		Vec3 a(sin(t) * 1.6, cos(t / 2) * 0.6, cos(t) * 1.25); // favourite coefficients: 1.6/0.6/1.25
		Vec3 b(sin(t) * 0.87, sin(t / 2) * 1.25, cos(t) * 1.15); // 0.87/1.25/1.15

		a = a * m; //rotate around sphere
		b = b * m;

		//a /= 4;
		//b /= 4;
		//a.z += 2;
		//b.z += 2;
		Vec3 aa = a + centerA;
		Vec3 ba = b + centerA;
		engine.sst.TransformSphere(aa); //lines are drawn in 3d space around a centre point, project lines onto a sphere
		engine.sst.TransformSphere(ba);
		//gfx.drawLineDepth(aa, ba, c);

		gfx.drawLineDepth(aa,ba, hue1, hue2, fade);
		a += centerB;
		b += centerB;
		engine.sst.TransformSphere(a);
		engine.sst.TransformSphere(b);
		gfx.drawLineDepth(a, b, hue1+60, hue2+60, fade);
	}

	Vec3 centerA = Vec3(0, 0, 0);
	Vec3 centerB = Vec3(0, 0, 0);
	Mat3 m;
	float offset = 0;
	float angle = 0;
};

class PatternParametric2 : public _Pattern {
public:
	PatternParametric2() : _Pattern("Parametric Spiral") {}


	uint8_t drawFrame() {
		if (!_Pattern::useCustomEffect) {
			gfx.fade(30);
			gfx.blur(90);
		}

		gfx.resetZ();
		const int maxI = 100;
		float step = (PI) / (maxI - 1);
		m = Mat3::RotationY(angle)  * Mat3::RotationX(angle);
		for (int i = 0; i < maxI; i++) {
			float t = offset + i * step;
			drawLine(t, i / 1, i / 1 + 32, min(i * 8, 255));
		}


		offset += 0.05;

		float radius = myMap(Data::sampleAvg, 0, Data::audioThreshold * 2, 2.5, 1.8, true);

		centerA.x = radius * cos(angle + PI);
		centerA.z = radius * sin(angle + PI);

		centerB.x = radius * cos(angle + PI + PI);
		centerB.z = radius * sin(angle + PI + PI);

		angle += 0.005;
		if (angle >= TWO_PI)
			angle -= TWO_PI;

		return returnVal;
	}

	void drawLine(float t, uint8_t hue1, uint8_t hue2, uint8_t fade) {
		//https://math.stackexchange.com/questions/324527/do-these-equations-create-a-helix-wrapped-into-a-torus
		float fa = 2.5;
		float fb = 1.4;
		//float k = 0.05;
		float u = 2*t;
		float v = t*.75;
		float x1 = (fa + fb * cos(u)) * cos(v);
		float z1 = (fa + fb * cos(u)) * sin(v);
		float y1 = fb * sin(u);
		//v -= PI/16;
		u += PI ;
		float x2 = (fa + fb * cos(u)) * cos(v);
		float z2 = (fa + fb * cos(u)) * sin(v);
		float y2 = fb * sin(u);
		Vec3 a(x1, y1, z1);
		Vec3 b(x2, y2, z2);
		//Vec3 a(2.5 * cos(t+PI) + cos(t+PI/4)*cos(4*t+PI/2),		 sin(4*t+PI/2),		2.5 * sin(t) + sin(t + PI / 4)*sin(4*t+PI/2)); // 1.6/0.6/1.25
		//Vec3 b(2.5 * cos(t+PI) + cos(t)*cos(4*(t + PI/2)), sin(4*(t+PI/2)),	2.5 * sin(t) + sin(t)*sin(4*(t+PI/2))); // 0.87/1.25/1.15

		a = a * m;
		b = b * m;

		//a /= 4;
		//b /= 4;
		//a.z += 2;
		//b.z += 2;
		//Vec3 aa = a + centerA;
		//Vec3 ba = b + centerA;
		//engine.sst.TransformSphere(aa);
		//engine.sst.TransformSphere(ba);
		//gfx.drawLineDepth(aa, ba, c);

		//gfx.drawLineDepth(aa, ba, hue1, hue2, fade);
		//a += centerB;
		//b += centerB;
		engine.sst.TransformSphere(a);
		engine.sst.TransformSphere(b);
		gfx.drawLineDepth(a, b, hue1 + 60, hue2 + 60, fade);
	}

	Vec3 centerA = Vec3(0, 0, 2.5);
	Vec3 centerB = Vec3(0, 0, -2.5);
	Mat3 m;
	float offset = 0;
	float angle = 0;
};

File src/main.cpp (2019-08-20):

#if defined(ARDUINO)
#else


#include "ofMain.h"
#include "ofApp.h"

//========================================================================
int main( ){
	ofSetupOpenGL(1024,768,OF_WINDOW);			// <-------- setup the GL context

	// this kicks off the running of my app
	// can be OF_WINDOW or OF_FULLSCREEN
	// pass in width and height too:
	ofRunApp(new ofApp());

}


#endif

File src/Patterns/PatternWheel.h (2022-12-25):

#pragma once

#include "Pattern.h"
#include "../../data.h"
#include "../Particle.h"

class PatternWheelBlur : public _Pattern {
public:
	PatternWheelBlur() : _Pattern("Wheel") {
	}


	uint8_t drawFrame() {

		for (uint8_t i = 0; i < 6; i++) {
			uint8_t x = offset + ((cos8(angle / 32) - 128) / 256.0) * myMap(i, 0, (6 - 1), -30, 30);
			uint8_t y = (SCREEN_HEIGHT / 2) + ((sin8(angle / 32) - 128) / 256.0) * myMap(i, 0, 6 - 1, -30, 30);
			CRGB c = gfx.getColour((i * 12)  + random8(10));
			x %= SCREEN_WIDTH;
			gfx.putPixel(x, y, c);
			c = gfx.getColour((i * 12) + random8(10));
			gfx.putPixel(x + 1, y, c);
			c = gfx.getColour((i * 12) + random8(10));
			gfx.putPixel(x, y + 1, c);
			c = gfx.getColour((i * 12) + random8(10));
			gfx.putPixel(x + 1, y + 1, c);
		}

		if (!_Pattern::useCustomEffect) {
			gfx.blur(75); // 75 works well for blur
		}

		offset += 0.25;
		angle += 20;
		//offset %= SCREEN_WIDTH;
		
		return returnVal;
	}

	float offset = 0;
	int angle = 0;

};


//class PatternWheelBlur2 : public _Pattern {
//public:
//	PatternWheelBlur2() : _Pattern("Wheel 2(PS)") {
//	}
//
//	class WheelSystem : public ParticleSystem {
//	public:
//		uint16_t x = 0;
//		uint16_t offset = 0;
//
//		Particle getParticle() {
//			const uint8_t maxSpokes = 6;
//			static uint8_t nextSpoke = 0;
//			Particle p;
//			p.pos.x = offset + x + (cos8(x / 32) - 128) * map(i, 0, (maxSpokes - 1), -32, 32);
//			p.pos.y = (SCREEN_HEIGHT / 2) * STEP + (sin8(x / 32) - 128) * map(i, 0, maxSpokes - 1, -32, 32);
//			p.vel.y = random(20) - 10;
//				p->vx = random(20) - 10;
//				p->hue = (baseHue / baseHueScale + random8(26) + i * 12) % 256;
//				p->alpha = 255;//random(25, 255);
//			}
//			nextSpoke++;
//			nextSpoke %= maxSpokes;
//		}
//		void run() {
//			offset += 5;
//			offset %= SCREEN_WIDTH * STEP;
//			x += 30;
//			x %= SCREEN_WIDTH * STEP;
//			for (uint16_t i = 0; i < MAX_PARTICLES; i++) {
//				Particle *p = &particles[i];
//				if (p->isDead()) {
//					continue;
//				}
//				else {
//					p->allFlock(particles);
//					p->update();
//					if (p->alpha - 10 < 0) p->alpha = 0;
//					else {
//						p->alpha -= 10;
//						p->show();
//						Particle offsetP = Particle(p);
//						offsetP.x = (offsetP.x + SCREEN_WIDTH * STEP / 2) % (SCREEN_WIDTH * STEP);
//						offsetP.y = SCREEN_HEIGHT * STEP - 1 - offsetP.y;
//						offsetP.show();
//					}
//
//				}
//			}
//		}
//	} ps;
//
//	uint8_t drawFrame() {
//
//		for (uint8_t i = 0; i < 6; i++) {
//			uint8_t x = offset + ((cos8(angle / 32) - 128) / 256.0) * myMap(i, 0, (6 - 1), -30, 30);
//			uint8_t y = (SCREEN_HEIGHT / 2) + ((sin8(angle / 32) - 128) / 256.0) * myMap(i, 0, 6 - 1, -30, 30);
//			CRGB c = gfx.getColour((i * 12) + random8(10));
//			x %= SCREEN_WIDTH;
//			gfx.putPixel(x, y, c);
//			c = gfx.getColour((i * 12) + random8(10));
//			gfx.putPixel(x + 1, y, c);
//			c = gfx.getColour((i * 12) + random8(10));
//			gfx.putPixel(x, y + 1, c);
//			c = gfx.getColour((i * 12) + random8(10));
//			gfx.putPixel(x + 1, y + 1, c);
//		}
//
//		if (_Pattern::useDefaultEffect) {
//			gfx.blur(75); // 75 works well for blur
//		}
//
//		offset += 0.25;
//		angle += 20;
//		//offset %= SCREEN_WIDTH;
//
//		return returnVal;
//	}
//
//	float offset = 0;
//	int angle = 0;
//
//};

class particleFountain : public ParticleSystem {
public:
	particleFountain() {}

	Particle getParticle() {
		static bool lastSide = true;
		Particle p;
		p.pos = Vec3(0.0f, 1.5f, 0.0f);
		float t;
		if (lastSide)	t = theta;
		else			t = TWO_PI - theta;
		//lastSide = !lastSide;
		p.pos.x = 2.1 * cos(t);
		p.pos.z = 2.1 * sin(t);

		float vy = myMap(Data::sampleAvg, 0, Data::audioThreshold * 2,-1.4, -1.8, true);

		p.vel.x = 0.5 * cos(t*6); //initial 0.5
		p.vel.z = 0.5 * sin(t*6);
		p.vel.y = -1.45;// (GuiVars2 - 1);
		//p.vel = { GuiVars1 - 1, GuiVars2 - 1, GuiVars3 - 1 };
		//p.vel *= 0.1; // -0.1 to 0.1
		p.vel *= 0.1;
		Vec3 ran = Vec3::getRandom(); //-1 to 1
		ran *= 0.02;
		p.vel += ran;
		//p.vel *= 0.1;
		p.acc = Vec3(0.0f, 0.0f, 0.0f);
		p.alpha = 255.0f;
		p.col = gfx.getColour(random8(30) + (t)* 6);
		p.hue = int(Data::getHue() + random8(30) + (t) * 6) % 256;
		p.mass = 1.0f;
		return p;
	}
	void incTheta(float d = 0.02) {
		theta += d;
		if (theta > TWO_PI)
			theta -= TWO_PI;
	}

	virtual void decreaseLife(Particle &p) {
		p.alpha -= 1.5f;
	}

	float theta = 0;

};

class PatternFountain : public _Pattern {
public:
	PatternFountain() : _Pattern("Particle fountain") {
	}

	void start() {
		ps.init();
		ps.limit = true;
	}
	void stop() {
		particles.clear();
	}
	uint8_t drawFrame() {
		gfx.resetZ();
		if (!_Pattern::useCustomEffect) {
			gfx.fade(128);
		}
		//ps.applyForce(Vec3(0.0f, 0.005*(GuiVars6-1), 0.0f)); // gravity
		ps.applyForce(Vec3(0.0f, 0.0075, 0.0f)); // gravity
		ps.addParticle();
		//ps.addParticle();
		ps.run();
		ps.incTheta();
		return returnVal;
	}
	particleFountain ps;
};
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

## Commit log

2019-08-21 SmoothColor
    SmoothColor shader working on both teensy and VS
2019-08-22 Update TeensyEngine.ino
    type
2019-08-22 working on arduino
2019-08-23 Fixed wrap around for cube
    [Graphics.h]
2019-08-23 super sampling tests - too much extra memory
    [Color.h, Graphics.h]
2019-10-03 var control and trigger rework
    [VariableControl.h]
2019-10-07 UI on teensy
2019-10-19 purpleRain and async UI DMA updates
2019-11-01 Updated patterns and fixed menu
    [Effects.h, Graphics.h, GraphicsFastLED.h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]
2019-11-15 Fixed patterns to use centralised blur. Added volts + amp sensing
    [Graphics.h, PatternParametric.h, PatternWheel.h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]
2019-12-09 Alpha to text, fixed fx for patterns
    [Graphics.h, GraphicsFastLED.h, Menu.h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]
2019-12-09 trying to add pitch/roll control
2019-12-10 Added water ish accelerometer aware pattern
2019-12-11 fix floor
    i.e limit amount particle can fall & add some bounce when hitting floor
    [PatternWheel.h]
2019-12-12 edits for teensy compiling
2019-12-17 adding hardware details
    [Connector.brd, Connector.sch, Totem Teensy.brd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]
2020-03-09 gp edits, work on audio and minor fixes
    [Menu.h, VariableControl.h, audio.h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]
2022-11-05 fixed volt/amp measurements. added mario images
    [Menu.h, TeensyEngine.ino, audio.h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]
2022-11-05 fire fixed on pc
    [ui.h]
2022-11-08 flower pattern start
2022-11-08 flower with rotate
2022-11-08 flowers almost completed - added roses and tulips
2022-11-08 flower complete, refactored slightly for arduino
2024-03-20 Added 3d model files
    fusion360 + unchecked step format, recommend to use fusion 360 to isolate and print parts

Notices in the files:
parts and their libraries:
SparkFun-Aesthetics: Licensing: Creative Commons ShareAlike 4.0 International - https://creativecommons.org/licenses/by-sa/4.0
